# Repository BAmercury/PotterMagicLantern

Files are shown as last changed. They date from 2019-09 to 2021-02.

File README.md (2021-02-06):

# PotterMagicLantern                                                                   
                                        |                                       
                                      |||||                                     
                                     || | ||                                    
                                   ||   |   ||                                  
                                  ||    |    ||                                 
                                || ||||||||||| ||                               
                               |||      |      |||                              
                              ||        |        ||                             
                            |||         |         |||                           
                           |||          |          |||                          
                         ||  |          |          |  ||                        
                        ||   ||         |         ||   ||                       
                      ||       ||       |       ||       ||                     
                     ||          |||    |    |||          ||                    
                   |||||||||||||||||||||||||||||||||||||||||||

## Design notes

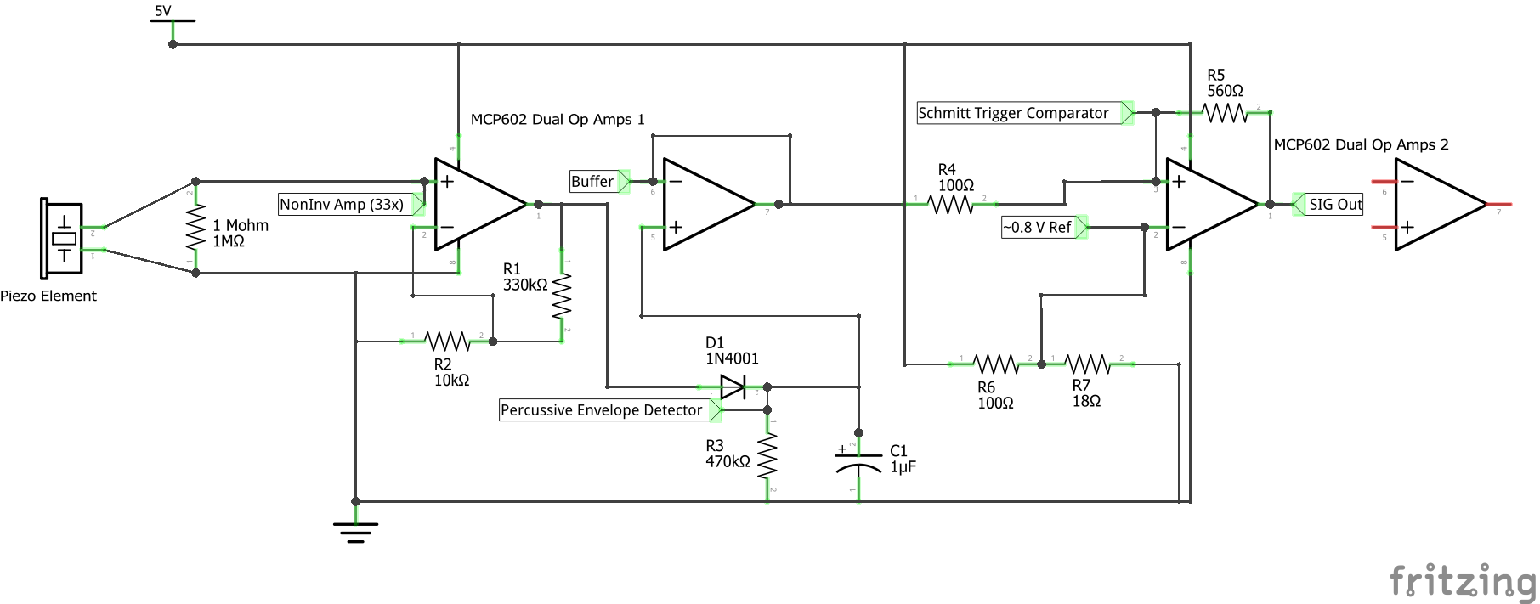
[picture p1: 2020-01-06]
Schematics/Lantern_schem.png

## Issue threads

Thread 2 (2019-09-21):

Resources

BAmercury, 2019-09-21:
Quick Links

BAmercury, 2019-09-21:
https://stackoverflow.com/questions/27755271/how-to-invoke-a-method-located-inside-the-android-project-from-the-portable-clas

BAmercury, 2019-09-21:
https://docs.microsoft.com/en-us/xamarin/xamarin-forms/app-fundamentals/dependency-service/photo-picker

BAmercury, 2019-09-29:
Think I'm going to pivot and instead of developing a bluetooth enabled interface maybe set up a Wifi enabled interface to make the device a bit more IoT friendly? https://create.arduino.cc/projecthub/electropeak/speak-to-arduino-and-control-it-with-google-assistant-3791ee

Closed 2020-07-10.

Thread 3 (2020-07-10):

Program ESP-01

BAmercury, 2020-07-10:
Program ESP-01:

- Connect to Adafruit IO Service
- Use a hidden config.h file
- Set a GPIO pin high to indicate ON/OFF toggle

BAmercury, 2020-07-10:
https://www.youtube.com/watch?v=ji71cHaGW8w

Found the best way to upload code to the esp-01 module is to do the following:

Make sure Arduino RST wire is grounded
Unplug TX/RX from arduino as well as power and ground
Power and Ground into ESP and then hit the rst button, make sure gpio0 is grounded
Blue light should show on the ESP-01 to indicate it's programmable
add tx/rx wires back and click upload

BAmercury, 2020-07-10:
https://www.instructables.com/id/How-to-use-the-ESP8266-01-pins/

BAmercury, 2020-07-11:
Code is working now, changes output on GPIO pin based on adafruit IO toggle switch. Programming it wasn't that bad, just need to make sure Arduino RST pin is grounded, and the ESP-01 is in programming mode by adding a reset button/grounding the GPIO0 pin. Getting it to work with the serial monitor is a bit of a pain it's a mix of turning the ESP-01 on/off, unplugging and plugging the reset pin on the Arduino, and clicking the reset button on the ESP-01

Closed 2020-07-11.

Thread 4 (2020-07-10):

Arduino integrate ESP-01

BAmercury, 2020-07-10:
Add code in Arduino to detect HIGH/LOW signal from ESP module showing when adafruit IO service was triggered

BAmercury, 2020-07-10:
Idea is to set another interrupt pin to the esp-01 gpio2 pin. Then I'll need a function that gets called on a timer to check the states of the esp as well as the piezo sensor and then enables/disables the animation

BAmercury, 2020-07-10:
Ideally the user should hit first before speaking the spell so maybe I could add that logic in there as well somehow

BAmercury, 2020-07-11:
ESP-01 GPIO2 pin is 3.3V will probably need to do analog in and just set a threshold

BAmercury, 2020-08-17:
Added it as an interrupt, tested it with a button sending out 3.3V and it seems to be working fine. Code has the spell turn on the animation when 2 strikes are given (shown by the status LED) and turns off the animation right away after the augamenti spell is spoken. Havne't tested it with the ESP32 wired up. I have a switch added in to allow the user to choose between the default fire animation and the other animations. If the other animations are enabled, the user can strike the lamp with the wand so cycle through 3 alternative animations.  I might remove the switch later and just have the user be able to cycle through all animations but right now I need to change the code to update without using the blocking delay() function

Closed 2020-08-17.

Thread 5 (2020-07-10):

Change code to analog input from interrupt

BAmercury, 2020-07-10:
Might take the comparator off the circuit and just have the arduino use the ADC to sample the output and set a programmable threshold to detect the hits instead. Concern is that the circuit won't trigger the arduino interrupt reliably or consistently

BAmercury, 2020-07-10:
also need to add some sort of timeout so if the lamp gets jostled or something it'll eventually clear out the strikes

BAmercury, 2020-07-10:
could probably add that logic described above to another main timing loop that checks the state of both the piezo sensor as well as the esp

BAmercury, 2020-07-10:
Actually came up with a pretty good idea:

1 interrupt setup to check the ESP-01 output.  This sets a global variable showing that a spell was spoken

A second timer is set at the beginning that checks this value. If this value is true, then this loop will routinely check for analog input from the piezo sensor looking for two strikes. This enables it so it'll only look for strikes when a spell is spoken. Otherwise it won't normally be checking so if the lamp ever gets jostled or moves around it won't trigger any false positives.

I won't have to add a timeout, I'll just set the center LED to indicate the spell was spoken, two strikes and it'll come on. When the user speaks aguamenti to turn the lamp off the gpio pin will change and the interrupt should trigger and change that spoken variable back to false, in the second timing loop it'll clear the # strikes and wait again till that variable turns true.

I will have to put together a state diagram to better explain this before I start coding

BAmercury, 2020-08-15:
Still brainstorming on the best way to go about this, but going to branch and experiment around

BAmercury, 2020-08-17:
Decided to keep both inputs as interrupts. Figured it would be nice to continue to strike the lamp to switch through the animations and the circuit does a lot already to ignore small pertubations and jostles. This version is meant to be stationary/plugged in so I shouldn't expect the system to have random disturbances. Even with random disturbances you still need to speak the spell to actually turn the lamp on/off. Added a status LED to indicate two strikes were given, meaning the spell is ready to be spoken.

Closed 2020-08-17.

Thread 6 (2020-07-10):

change animation switch or button

BAmercury, 2020-07-10:
add either a toggle button or a three way switch to button of lamp so I can change between the types of animations

BAmercury, 2020-08-17:
I have it set so the user can strike the lamp to ch ange through the animations (aside from the default fire animation - which can be toggled using a switch at the bottom of the lamp. It might be smarter to be able to cycle through all animations through striking so I might change it to that. But first I need to change all the code to stop using the delay() blocking function to setting the timer values using millis()

BAmercury, 2020-08-17:
Referencing this code to update the Adafruit animations: https://github.com/ndsh/neopixel-without-delay

BAmercury, 2020-08-17:
Now you can cycle throw all animations by striking the lamp, removed the whole toggle switch thing. Convereted the animations to use millis instead of delay - but the fire animation will need to be re-written to work like this

BAmercury, 2021-02-06:
Fire animation is rewritten to work with the millis(), but the issue is the update rate. It's animating too fast so need to tune an appropriate time interval to make it look realistic and smooth

BAmercury, 2021-02-06:
lol I'm dumb - found the issue:
```c
// Read animation files from Colors.h and convert to RGB. Output to Neopixel strip
void animate_led()
{
  uint8_t h, s, l;
  hsl_values hsl;
  for (int i = 0; i < sizeof(colors) / 3; ++i)
  {
    //Read the the next color from progmem
		h = pgm_read_byte_near(colors + (i * 3));
		s = pgm_read_byte_near(colors + (i * 3) + 1);
		l = pgm_read_byte_near(colors + (i * 3) + 2);

    hsl.h = (float)h / 255;
    hsl.s = (float)s / 255;
    hsl.l = (float)l / 255;
    rgb_values rgb;
    rgb = hsl2RGB(hsl);

    for (int j = 0; j <= NUM_LED; j++)
    {
      strip.setPixelColor(j, rgb.red, rgb.blue, rgb.green);
    }
    strip.show();
    // Updates every 33 ms (Can use this to control framerate of animation)
    //delay(33);

  }

}
```

The for loop is an issue, need to rewrite this function to support millis()

BAmercury, 2021-02-06:
was able to fix the issue by removing the for loop and writing 2 new functions. one iterates through the colors array and one keeps track of the index and updates the LEDs. seems to be working now. may need to edit the time period value later but seems to be okay for now

Closed 2021-02-06.

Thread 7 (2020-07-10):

Voltage source for ESP-01

BAmercury, 2020-07-10:
Breadboard the finished ESP-01 and try a voltage divider to give it 3.3V. Ideally I should've gotten a voltage regulator for 3.3V but I don't have one on hand

BAmercury, 2020-07-11:
Going to try to put together a breadboard with the voltage divider since the ESP is programmed, will use a multimeter to monitor the GPIO2 output and see how the device behaves when powered from the voltage divider.

Then I'll update the fritzing diagram to document the pinout

BAmercury, 2020-07-11:
Don't think the voltage divider will work might need to rush order some 3.3v regulators

BAmercury, 2020-08-15:
Got a 3.3V regulator just for the ESP: https://www.sparkfun.com/datasheets/Components/LD1117V33.pdf

Closed 2020-08-15.

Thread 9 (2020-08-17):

update fritzing schematic

BAmercury, 2020-08-17:

BAmercury, 2020-08-17:
Need to add the ESP32, voltage regulators (3.3V and 5V), arduino uno + it's associated components, neopixel and it's associated components

BAmercury, 2021-02-06:
added ESP8266, 3.3V regulator - but not associated components, need to do that. Added filtering cap 1000 uF, arduino uno, neopixel ring, pot, status led it's coming along. May need to clean up the nets for the perfboard layout later

BAmercury, 2021-02-06:
need to add discrete atmega238p schematic

BAmercury, 2021-02-06:
https://www.arduino.cc/en/main/standalone

BAmercury, 2021-02-06:
https://voidyourwarranty.wordpress.com/2014/08/17/using-arduino-as-an-isp-to-program-a-standalone-atmega-328p-including-fuses/

Been very helpful

BAmercury, 2021-02-06:
Using this 16 MHz Crystal: https://www.arrow.com/en/products/12.84485/geyer-electronic
Speccing caps:
https://blog.adafruit.com/2012/01/24/choosing-the-right-crystal-and-caps-for-your-design/

BAmercury, 2021-02-06:
New issue, I don't have 2 22pF caps needed for the 16Mhz crystal...I can attempt to use the internal 8 Mhz clock for now:
 https://github.com/MCUdude/MiniCore
https://www.arduino.cc/en/Tutorial/BuiltInExamples/ArduinoToBreadboard
Gonna give it a go and see what happens

BAmercury, 2021-02-06:
https://www.circuito.io/blog/atmega328p-bootloader/

BAmercury, 2021-02-06:
make sure when burning bootloader to select "Arduino as ISP (MInicore)

BAmercury, 2021-02-06:
Speccing a 5V voltage regulator" https://www.baldengineer.com/regulator-basics.html

BAmercury, 2021-02-06:
I can either go w/ a 5V supply and decoupling caps or step up my voltage for the dropout and use the regulator
http://www.thebox.myzen.co.uk/Tutorial/De-coupling.html

BAmercury, 2021-02-06:
https://www.avrfreaks.net/forum/decoupling-capacitor-vcc-pin
"100nF" per VCC pin decoupling caps

BAmercury, 2021-02-06:
Think I'll go with my 9V 1.5A power supply, and add the regulator (5V and 3.3V)

BAmercury, 2021-02-06:
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

BAmercury, 2021-02-07:
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

BAmercury, 2021-02-07:
So 8 Mhz seems to run the code, the fire animation is having the framerate issue again where it's animating too fast so might need to adjust the interval values..or wait till tuesday for the caps to come in for the 16 Mhz oscillator

BAmercury, 2021-02-09:
Caps came in, going to update the schematic and throw the whole project on a breadboard to test, including the piezo circuit. just need to make some breakouts for some components

BAmercury, 2021-02-09:
https://arduino.stackexchange.com/questions/37075/correct-capacitors-to-use-with-l7805-voltage-regulator

BAmercury, 2021-09-01:
https://shallowsky.com/blog/hardware/programming-breadboard-atmega.html

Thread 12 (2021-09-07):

ESP-01 Schematic for programming via ftdi

BAmercury, 2021-09-07:
New schematic for an ESP-01 programming board using an ftdi chip

BAmercury, 2021-09-07:
I have a 5V FTDI board so will need a logic level converter

BAmercury, 2021-09-07:
So to upload a program to the ESP-01:
1. Power on the module
2. Connect the RESET pin to GND
3. Connect GPIO-0 pin to GND
4. Disconnect Reset Pin from GND
5. Disconnect GPIO-0 pin from GND
6. Upload the sketch

BAmercury, 2021-09-07:
https://www.instructables.com/ESP8266-Programming-Using-FTDI-and-Arduino-IDE/

https://circuitdigest.com/microcontroller-projects/getting-started-with-esp8266-module

https://www.instructables.com/ESP-01-Module-Programming-Board/

https://www.sparkfun.com/products/12009

https://www.sparkfun.com/products/9716

BAmercury, 2021-09-07:
- [ ] Assemble logic level converter
- [ ] Setup circuit on breadboard
- [ ] Test upload
- [ ] Layout on perfboard
- [ ] assemble perfboard

BAmercury, 2022-05-24:
Just assembled perfboard, need to test it

BAmercury, 2023-09-05:
"If a blue light will switch on momentarily on the ESP module, then your ESP is in programming mode."

BAmercury, 2023-09-05:
Board doesn't seem to be working. Checked at the vcc/ground pins of the ESP8266 model and seeing 0V, even though I checked for connectivity and it was fine. Maybe the logic level shifter board cannot supply the ESP8266 model with adequate voltage?

BAmercury, 2023-09-05:
on the breadboard I connected the ESP-01 module to a 3.3V power source and the red power light came on, so I am assuming the logic level shifter is not sufficient enough to power the board, idek why i thought that was a good idea lol

BAmercury, 2023-09-05:
Using these logic level shifters: https://www.amazon.com/gp/product/B07LG646VS/ref=ppx_yo_dt_b_search_asin_title?ie=UTF8&psc=1

They are showing 3.3V on the out supply side but maybe it's not enough to drive the ESP-01 LED

BAmercury, 2023-09-05:
Think on my perfboard I must've flipped the LV and GND pin connections between the logic level shifter and the ESP-01 headers

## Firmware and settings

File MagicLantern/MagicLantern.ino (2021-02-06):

#include <Adafruit_NeoPixel.h>
#include "Colors.h"
#include <Smoothed.h>

#define PIN_LED_DATA 8
#define PIN_STATUS_LED 6 // PWM Pin for analogWrite
#define INTERRUPT_PIN_SENSOR_INPUT 2 // piezo circuit digital output
#define INTERRUPT_PIN_ESP_INPUT 3 // ESP32 digital output
#define PIN_POT 1 // Analog input pin 1
#define NUM_LED 24

//   NEO_KHZ800  800 KHz bitstream (most NeoPixel products w/WS2812 LEDs)
Adafruit_NeoPixel strip = Adafruit_NeoPixel(NUM_LED, PIN_LED_DATA, NEO_GRB + NEO_KHZ800);

unsigned long animate_prev_ms = 0;
unsigned long main_loop_prev_ms = 0;
unsigned long fire_interval = 33; // milliseconds
unsigned long rainbow_interval = 10; // milliseconds
unsigned long theater_interval = 50; // milliseconds
unsigned long main_loop_interval = 10; // milliseconds


// Animations:
// 0: Fire
// 1: RainbowCycle
// 2: theaterChaseRainbow 
// 3: Wheel
volatile int desired_animation = 0; 
int desired_animation_cpy = 0;
int prev_desired_animation = 0;
bool animate = true;


// Potentiometer Sensor
Smoothed <int> PotSensor;
const int WINDOW_SIZE = 10; // Window size for MA filter running for the pot


// Count amount of taps
volatile int two_tap_count = 0;
volatile int cycle_mode = 0;
// If 2 taps received update this boolean
volatile bool two_taps = false;
bool two_taps_cpy = false;

void sensor_tap_counter()
{
    two_tap_count++;
    // If we received two taps, update the control boolean for the main loop
    if (two_tap_count > 2)
    {
        two_taps = true; // This boolean latches and does not get reset until augamenti is spoken
        // Reset tap counter
        two_tap_count = 0;
    }

    // if we have already tapped twice assume the animation is running
    if (two_taps)
    {
        if(++cycle_mode > 4) cycle_mode = 0; // Advance to next mode, wrap around after 3
        switch (cycle_mode)
        {
            case 0:
                desired_animation = 0; // Fire
                break;
            case 1:
                desired_animation = 1; // Rainbow Cycle
                break;
            case 2:
                desired_animation = 2; // Theater
                break;
            case 3:
                desired_animation = 3; // Rainbow Solid
        }
    }
    

}

volatile bool esp_state = false;
bool esp_state_cpy = false;
void esp_state_change()
{
    // Flip the control boolean for every detected state change
    esp_state = !esp_state;
}



void setup()
{
    Serial.begin(115200);
    strip.begin();
    strip.show();
    pinMode(PIN_STATUS_LED, OUTPUT);
    pinMode(INTERRUPT_PIN_SENSOR_INPUT, INPUT);
    pinMode(INTERRUPT_PIN_ESP_INPUT, INPUT);
    attachInterrupt(digitalPinToInterrupt(INTERRUPT_PIN_SENSOR_INPUT), sensor_tap_counter, RISING);
    attachInterrupt(digitalPinToInterrupt(INTERRUPT_PIN_ESP_INPUT), esp_state_change, RISING);

    // initialize the Pot Sensor
    PotSensor.begin(SMOOTHED_AVERAGE, WINDOW_SIZE);
}



void loop()
{


    // Run main loop in a programmmable interval
    // Checks status of control bools 
    if ((unsigned long)(millis() - main_loop_prev_ms) >= main_loop_interval)
    {
        main_loop_prev_ms = millis();
        
        // Disable interrupts and copy control booleans
        noInterrupts();
        esp_state_cpy = esp_state;
        two_taps_cpy = two_taps;
        desired_animation_cpy = desired_animation;
        //desired_animation_cpy = 0;
        interrupts(); // Reenable interrupts

        // Now check boolean logic

        // let user know we received two taps and awaiting for incendio spell
        if (animate == false && two_taps_cpy && esp_state_cpy == false)
        {
            digitalWrite(PIN_STATUS_LED, HIGH);
        }
        // If we received two hits and we have spoken the activation spell (incendio)
        if (two_taps_cpy && esp_state_cpy)
        {
            animate = true;
            // Setup the bookeeping timer variables
            animate_prev_ms = 0;
        }
        // If we have spoken the aguamenti spell, turn off the animation and reset variables
        if (animate && esp_state_cpy == false)
        {
            animate = false;
            esp_state_cpy = false;
            two_taps_cpy = false;
            animate_prev_ms = 0;
            digitalWrite(PIN_STATUS_LED, LOW);
            noInterrupts();
            // Reset some global variables
            two_tap_count = 0;
            interrupts();
            // Turn off all LEDs
            for (int j = 0; j <=NUM_LED; j++)
            {
                strip.setPixelColor(j, 0,0,0);
            }
            strip.show();
        }
        
    }
    // If the control bools are set, start the animation
    if (animate)
    {

        // Select and run the desired animation when the time is appropiate
        switch (desired_animation_cpy)
        {
            case 0:
                if ((unsigned long)(millis() - animate_prev_ms) >= fire_interval)
                {
                    animate_prev_ms = millis();
                    animate_led_interval(); // Run fire animation
                }
                break;
            case 1:
                if ((unsigned long)(millis() - animate_prev_ms) >= rainbow_interval)
                {
                    animate_prev_ms = millis();
                    rainbowCycle(); // Run Rainbow cycle animation
                }
                break;
            case 2:
                if ((unsigned long)(millis() - animate_prev_ms) >= theater_interval)
                {
                    animate_prev_ms = millis();
                    theaterChaseRainbow();
                }
                break;
            case 3:
                if ((unsigned long)(millis() - animate_prev_ms) >= rainbow_interval)
                {
                    animate_prev_ms = millis();
                    rainbow();
                }
                break;
        }
    }



}

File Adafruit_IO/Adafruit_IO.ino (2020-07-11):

/***************************************************  
Potter Lamp ESP-01 Module Code
Connects to Wifi and checks updates from Adafruit IO feed that is toggled using Google Assistant
References the following definitions from a config.h header file:
  WLAN_SSID
  WLAN_PASS
  AIO_SERVER
  AIO_SERVERPORT
  AIO_USERNAME
  AIO_KEY

  
Referenced code from:
  Tony DiCola for Adafruit Industries
 ****************************************************/
#include <ESP8266WiFi.h>
#include "Adafruit_MQTT.h"
#include "Adafruit_MQTT_Client.h"
#include "config.h"



// Create ESP8266 WifiClient class
WiFiClient client;

// Setup MQTT client, make sure to include config.h for credientials
Adafruit_MQTT_Client mqtt(&client, AIO_SERVER, AIO_SERVERPORT, AIO_USERNAME, AIO_KEY);


// Setup subscriber feeds
// MQTT Paths for Adafruit IO follow the form: <username>/feeds/<feedname>
Adafruit_MQTT_Subscribe spell_toggle = Adafruit_MQTT_Subscribe(&mqtt, AIO_USERNAME "/feeds/potterlamponoff");






// Bug workaround for Arduino 1.6.6, it seems to need a function declaration
// for some reason (only affects ESP8266, likely an arduino-builder bug).
void MQTT_connect();

void setup() 
{

  // Setup Serial
  Serial.begin(115200);
  delay(10);

  // Setup Pins (GPIO2)
  pinMode(2, OUTPUT);


  // Connect to Wifi Access Point
  Serial.println("Connecting to WIFI");
  // Connect to WiFi access point.
  WiFi.begin(WLAN_SSID, WLAN_PASS);
  while (WiFi.status() != WL_CONNECTED) {
    delay(500);
  }
  Serial.println("WiFi connected");
  Serial.println("IP address: "); Serial.println(WiFi.localIP());

  // Setup MQTT subscription for the lamp toggle feed
  mqtt.subscribe(&spell_toggle);

}

uint32_t x=0;

void loop() {
  // Ensure the connection to the MQTT server is alive (this will make the first
  // connection and automatically reconnect when disconnected).  See the MQTT_connect
  // function definition further below.
  MQTT_connect();

  // wait for incoming packets
  Adafruit_MQTT_Subscribe *subscription;
  while ((subscription = mqtt.readSubscription(5000))) 
  {
    if (subscription == &spell_toggle) 
    {

      Serial.println((char *)spell_toggle.lastread);
      // Toggle LED depending on status of the packet
      if ( !strcmp((char*) spell_toggle.lastread, "ON") )
      {
        // Set the GPIO2 Pin High
        digitalWrite(2, HIGH);
      }
      else
      {
        digitalWrite(2, LOW);
      }      
    }
  }
  // ping the server to keep the mqtt connection alive
  if(! mqtt.ping()) {
    mqtt.disconnect();
  }

}

// Function to connect and reconnect as necessary to the MQTT server.
// Should be called in the loop function and it will take care if connecting.
void MQTT_connect() {
  int8_t ret;

  // Stop if already connected.
  if (mqtt.connected()) {
    return;
  }

  Serial.print("Connecting to MQTT... ");

  uint8_t retries = 3;
  while ((ret = mqtt.connect()) != 0) { // connect will return 0 for connected
       Serial.println(mqtt.connectErrorString(ret));
       Serial.println("Retrying MQTT connection in 5 seconds...");
       mqtt.disconnect();
       delay(5000);  // wait 5 seconds
       retries--;
       if (retries == 0) {
         // basically die and wait for WDT to reset me
         while (1);
       }
  }
  Serial.println("MQTT Connected!");
}

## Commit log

2019-03-27 test file for piezo switch circuit, cleaned main led code
2019-03-27 Couldn't use timer properly so reverting back
    [InterruptDemo.ino, MagicLantern.ino]
2019-03-27 Works well with piezo mounted at base of lamp. Added in statements for changing animations need to add in serial checking subroutines
2019-03-27 attempting to draw up a circuit schematic in eagle
    [Lantern.sch]
2019-09-02 fixed some control logic
    [MagicLantern.ino]
2019-09-22 Started working on the app and cleaned up some arduino code
2019-10-15 Moving onto making it IoT Friendly
    [Lantern.fzz, Lantern.sch]
2019-10-19 ADC study uploading code
2020-01-05 Added sensor to control hue shift, needs testing
2020-01-06 Cleaned up schematic
    [Lantern.fzz]
2020-01-06 Debugging
    Need to add a trim pot for the comparator circuit
2020-07-11 ESP-01 is working and outputs to GPIO pin with updates
2020-08-16 Updates to integrate ESP32
    Added new logic to toggle main animation. Updated misc animations and have them able to toggle via tapping the lamp. Need to test
2020-08-17 Debugged and fixed code, need to speed up animation selection cycle
    [Fire.ino, MagicLantern.ino, OtherAnimations.ino]
2020-08-17 Changed from delay to using millis()
    Changed all animation code to use millis() to update instead of setting a delay. Should make the lamp more responsive. need to test
2020-08-17 So switching to millis works for all but the fire animation. need to fix
    [Fire.ino, MagicLantern.ino]
2021-02-06 Fixed fire animation framerate error
    Rewrote fire animation functions to work with an update millis() loop rather than delay()
    [Fire.ino, MagicLantern.ino]
